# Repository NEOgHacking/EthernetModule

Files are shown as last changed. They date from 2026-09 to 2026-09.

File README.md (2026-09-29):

# EthernetModule
This is a custom Ethernet module for the hackxpansion console made by @koeg. It has been created with some simple components. It was made for the purpose of having internet on the hackxpansion console via wire, or even to have local multiplayer.

## Design
This module has been designed with the following requirements and components
single slot hackxpansion module
W5500 PHY ic communicating over spi
Ethernet port with integrated magnetics
length and impedance matched
up to 100Mb/s speed

## Schematic



## PCB




## Case

https://cad.onshape.com/documents/23acd3255b900cc5b85fa1fc/w/7ef244823df79fb773706f50/e/06be5b5812756bedfbe98cc1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





## Code
I used the tutorial on the first driver heavily when writing the code for this module.

# Credits
# **@KOEG**

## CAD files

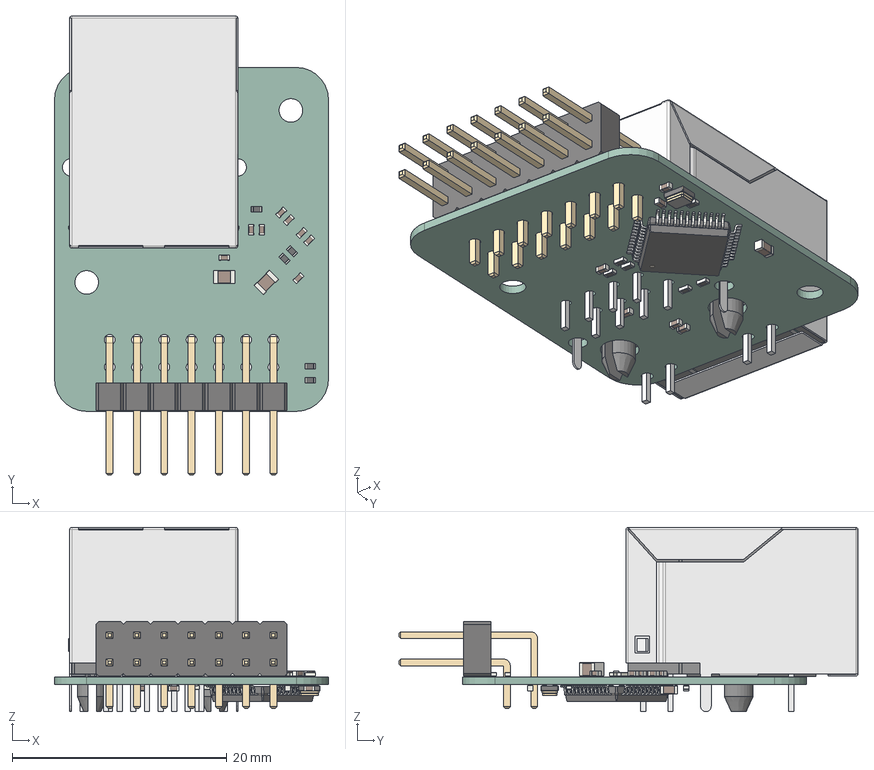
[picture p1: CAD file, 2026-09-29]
pcb/Ethernet_interface.step
25.5 x 42.7 x 17.1 mm
R_0402_1005Metric x 11
C_0402_1005Metric x 14
RJ45-TH_HR911105A
C_0805_2012Metric x 2
PinHeader_2x07_P254mm_Horizontal
LQFP-48_7x7mm_P0.5mm
Crystal_SMD_2016-4Pin_2.0x1.6mm
C_0603_1608Metric
Ethernet_interface_PCB

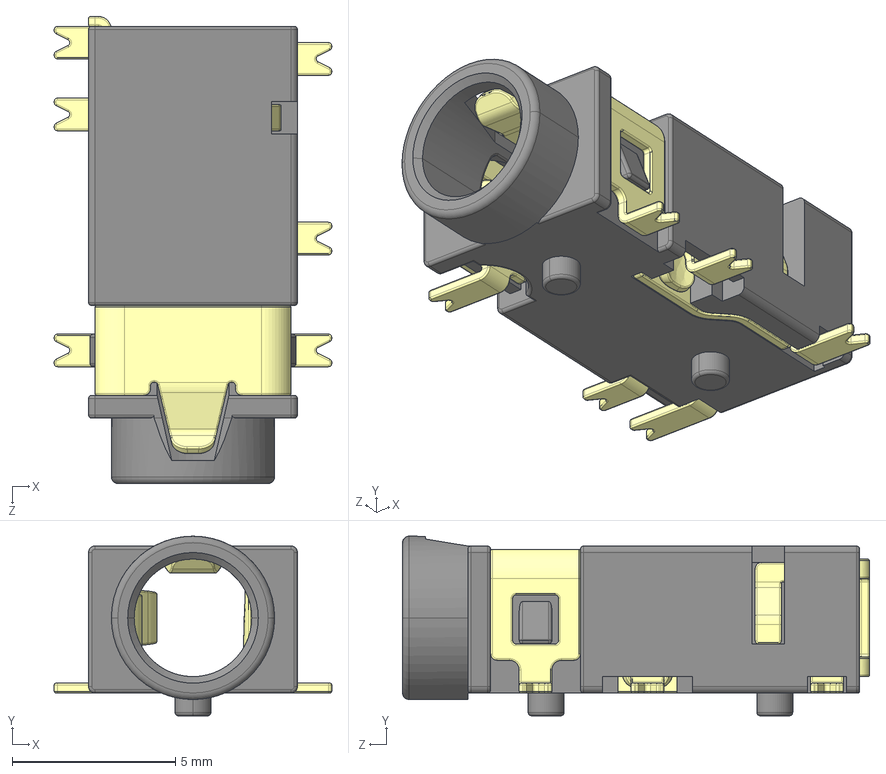
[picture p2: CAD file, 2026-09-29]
pcb/kicad_lib/PJ311D_WPos.STEP
8.50 x 5.50 x 14.3 mm
001^PJ311D_WPos
002^PJ311D_WPos
003^PJ311D_WPos
004^PJ311D_WPos
005^PJ311D_WPos
006^PJ311D_WPos
007^PJ311D_WPos

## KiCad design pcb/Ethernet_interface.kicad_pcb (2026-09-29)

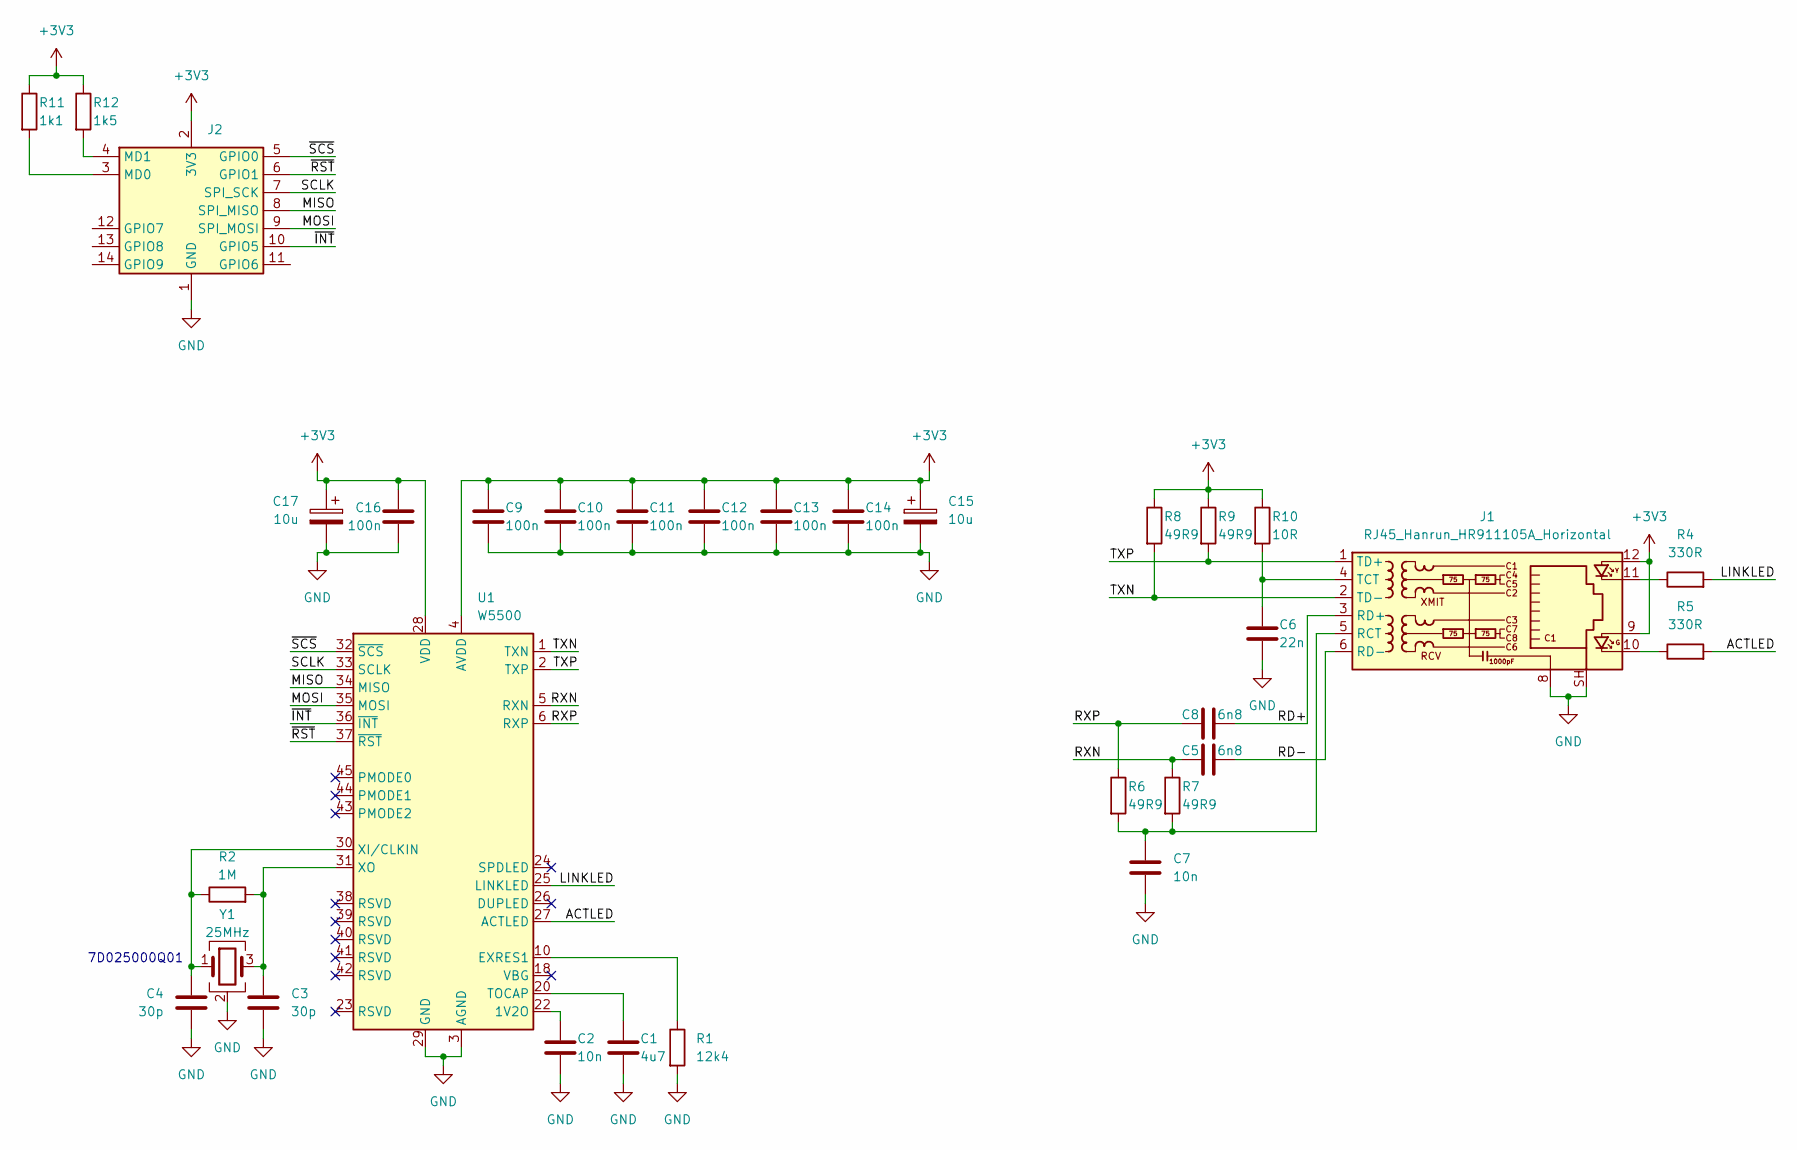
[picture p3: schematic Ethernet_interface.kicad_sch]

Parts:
C1: 4u7; C_0603_1608Metric
C2, C7: 10n; C_0402_1005Metric
C3, C4: 30p; C_0402_1005Metric
C5, C8: 6n8; C_0402_1005Metric
C6: 22n; C_0402_1005Metric
C9, C10, C11, C12, C13, C14, C16: 100n; C_0402_1005Metric
C15, C17: 10u; C_0805_2012Metric; LCSC C1969735
J1: RJ45_Hanrun_HR911105A_Horizontal; LCSC C12074
J2: PinHeader_2x07_P2.54mm_Horizontal
R1: 12k4; R_0402_1005Metric
R2: 1M; R_0402_1005Metric
R4, R5: 330R; R_0402_1005Metric
R6, R7, R8, R9: 49R9; R_0402_1005Metric
R10: 10R; R_0402_1005Metric
R11: 1k1; R_0402_1005Metric
R12: 1k5; R_0402_1005Metric
U1: W5500; LQFP-48_7x7mm_P0.5mm; LCSC C32843
Y1: 25MHz; Crystal_SMD_2016-4Pin_2.0x1.6mm; LCSC C648942

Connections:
+3V3: C9.1, C10.1, C11.1, C12.1, C13.1, C14.1, C15.1, C16.1, C17.1, J1.9, J1.12, J2.2 (3V3), R8.1, R9.1, R10.1, R11.1, R12.1, U1.4 (AVDD), U1.8 (AVDD), U1.11 (AVDD), U1.15 (AVDD), U1.17 (AVDD), U1.21 (AVDD), U1.28 (VDD)
/ACTLED: R5.2, U1.27 (ACTLED)
/LINKLED: R4.2, U1.25 (LINKLED)
/MISO: J2.8 (SPI_MISO), U1.34 (MISO)
/MOSI: J2.9 (SPI_MOSI), U1.35 (MOSI)
/RD+: C8.2, J1.3 (RD+)
/RD-: C5.2, J1.6 (RD-)
/RXN: C5.1, R7.1, U1.5 (RXN)
/RXP: C8.1, R6.1, U1.6 (RXP)
/SCLK: J2.7 (SPI_SCK), U1.33 (SCLK)
/TXN: J1.2 (TD-), R8.2, U1.1 (TXN)
/TXP: J1.1 (TD+), R9.2, U1.2 (TXP)
/~INT: J2.10 (GPIO5), U1.36 (~INT)
/~RST: J2.6 (GPIO1), U1.37 (~RST)
/~SCS: J2.5 (GPIO0), U1.32 (~SCS)
GND: C1.2, C2.2, C3.2, C4.2, C6.2, C7.2, C9.2, C10.2, C11.2, C12.2, C13.2, C14.2, C15.2, C16.2, C17.2, J1.8, J1.SH, J2.1 (GND), R1.2, U1.3 (AGND), U1.9 (AGND), U1.14 (AGND), U1.16 (AGND), U1.19 (AGND), U1.29 (GND), U1.48 (AGND), Y1.2 (G), Y1.4 (G)
unnamed: J1.10, R5.1
unnamed: J1.11, R4.1
unnamed: C7.1, J1.5 (RCT), R6.2, R7.2
unnamed: C6.1, J1.4 (TCT), R10.2
unnamed: J2.3 (MD0), R11.2
unnamed: J2.4 (MD1), R12.2
unnamed: C2.1, U1.22 (1V2O)
unnamed: R1.1, U1.10 (EXRES1)
unnamed: C1.1, U1.20 (TOCAP)
unnamed: C4.1, R2.1, U1.30 (XI/CLKIN), Y1.1
unnamed: C3.1, R2.2, U1.31 (XO), Y1.3

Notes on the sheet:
7D025000Q01

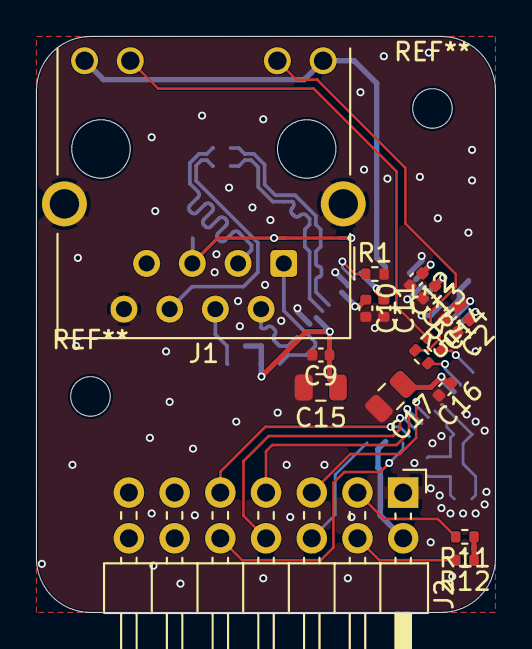
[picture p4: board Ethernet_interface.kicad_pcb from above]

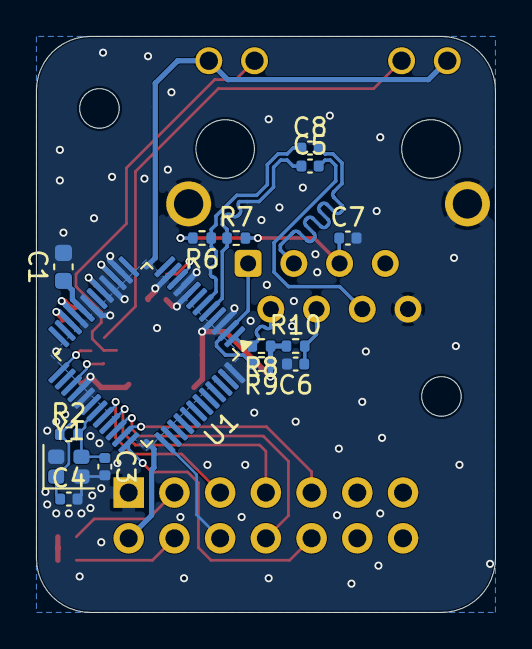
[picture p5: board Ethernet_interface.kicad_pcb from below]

Board: 2 copper layers, 25.5 x 32.0 mm, 32 parts (15 on the bottom side), 27 nets.

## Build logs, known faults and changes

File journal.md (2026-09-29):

# Journal 1 20m

# Brainstorm
So long story short i wanted internet and specifically Ethernet because who doesn't love a wire :yay: Well i did a bit of digging and most of the phys i found used in most devices need a special part in the microcontroller so to prevent that i went for the good old W5500 SPI ethernet phy. Then i went for the best selling Ethernet connector with integrated magnetics.



Apart from that it will be a very tight module but o well challenges are fun.

# Journal 2 90m

# Schematic
So at first i laid out all the ic's and connectors i needed. With the things i choose in the last journal



Then i started following the datasheet of the W5500 for the right capacitances and resistances needed for the different pins used first i started with the pins that were defined what stuff they needed in the pinout diagram.



Then i found the specs of the crystal i needed. I directly implemented that into the schematic as per datasheet rules.



After this i dug a bit deeper and did allot of decoupling for the voltage in.



Then i started on the Ethernet connector, at first i did the status leds for the ethernet connector so it would show the rights stuff you would expect it to show.



Then i started on the hardest part, the decoupling and resistors needed for the tx and rx pairs of the Ethernet connection, this is after 2 times still black magic for me but i just follow the datasheet of the W5500.



After some tries i got it done and had it laid out nicely that i was happy with.



Then i did the right labels for the Ethernet ic, the spi pins and the reset pins ext. the rest i stopped of with those cross thingies.



Now it was time to connect it to the module connector. This was a bit of a unknown. I only connected the pins that would need to go to specific pins so i could choose the pinout for the others while doing the PCB design so it would match the PCB better.



Then at the end a total of the schematic.



# Journal 3 300m

# PCB layout and routing

At first i started with the layout of the bigest components like the network connector the ic and the expansion connector, these would be the most irritatingly in the way so i wanted to get them out of the way as soon as possible.



Then i started with routing the most important traces off them all the ethernet pairs. I used the calculator from jlcpcb to calculate the impedance needed, tho for this short length it wouldn't matter much.



now it was time to do the next thing This was where i would want all the components, i also looked at other ethernet connectors but 90% of them where to long so this was the way to go.



Then i started with decoupling the ic and also adding the crystal for the ic, i decided on a 2 sided pcb because of the space constraints.



Now i had some more components placed down i needed to length match the tx trace, i did this and this worked, but just barely.



Next things next I started thinking about how i wanted to lay out the rx trace, it was really aquard spot and i had tried a few different things. Here i had a general idea of where i wanted the components that where needed in between the rx and tx traces.



The next picture was a small step of brainstorming the ethernet traces.



Then i routed the RX side and found out this is what i had to deal with.



So i tried a few different things but ended up here with this botched up trace so + and - of the RX trace would line up.



Then it was time for some length matching, and some was an understatement, 5mm for this was crazy but eah its what we have to do, im just gradefull i didn't need to lenght match rx to tx that would be terror.



Now time for the length matching here is its beutifull sight.



Then i routed the 3.3V power trace and the spi bus.



Now at the end, here are a few final pictures of the end product.











# Credits

# @KOEG

# Journal 4 60m

# Case

At first i imported the pcb into onshape as a step file with the 3d models so i could base the case off the 3d models.



Then i created a sketch that had a perimeter and some other features all included in the sketch so it would only take a few extrudes to finish it.



Then i extruded the perimeter on the outside of the case.



Now i created a top so it wouldn't be a open module.



Now it looked like this a bit not so nice, i wanted to create some fillits so it looked a bit nicer and here is a before and after.





# Credits

# **@KOEG**

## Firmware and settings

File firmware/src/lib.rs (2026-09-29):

#![no_std]

use xpanse_api::{
    bus::{allocator::BusAllocator, spi::SpiBusHandle},
    driver::{Driver, DriverError, DriverMeta},
    gpio_bank::{BankPins, GpioBank},
    metadata::{ModuleDetectResistor, ModuleID, ModuleSlot},
    reexports::embassy_rp::{
        gpio::{Level, Output},
        spi,
    },
    registry::Registry,
};

pub const SPI_SCK_GPIO: u8 = 2;
pub const SPI_MISO_GPIO: u8 = 3;
pub const SPI_MOSI_GPIO: u8 = 4;
pub const W5500_CS_GPIO: u8 = 0;

const COMMON_REG_BLOCK: u8 = 0;
const VERSION_REGISTER: u16 = 0x0039;
const EXPECTED_VERSION: u8 = 0x04;

pub struct EthernetDriver;

impl DriverMeta for EthernetDriver {
    const ID: ModuleID = ModuleID {
        md0: ModuleDetectResistor::R1K1,
        md1: ModuleDetectResistor::R1K5,
    };
}

pub struct W5500 {
    spi: SpiBusHandle,
    cs: Output<'static>,
}

impl W5500 {
    fn new(spi: SpiBusHandle, cs: Output<'static>) -> Self {
        Self { spi, cs }
    }

    pub async fn read_register(&mut self, block: u8, address: u16) -> Result<u8, W5500Error> {
        let mut value = [0];
        self.read(block, address, &mut value).await?;
        Ok(value[0])
    }

    pub async fn write_register(
        &mut self,
        block: u8,
        address: u16,
        value: u8,
    ) -> Result<(), W5500Error> {
        self.write(block, address, &[value]).await
    }

    pub async fn version(&mut self) -> Result<u8, W5500Error> {
        self.read_register(COMMON_REG_BLOCK, VERSION_REGISTER).await
    }

    pub async fn is_present(&mut self) -> Result<bool, W5500Error> {
        Ok(self.version().await? == EXPECTED_VERSION)
    }

    pub async fn read(
        &mut self,
        block: u8,
        address: u16,
        data: &mut [u8],
    ) -> Result<(), W5500Error> {
        let header = make_header(block, address, false)?;
        self.cs.set_low();
        let result = async {
            self.spi.write(&header).await.map_err(W5500Error::Spi)?;
            self.spi.read(data).await.map_err(W5500Error::Spi)
        }
        .await;
        self.cs.set_high();
        result
    }

    pub async fn write(&mut self, block: u8, address: u16, data: &[u8]) -> Result<(), W5500Error> {
        let header = make_header(block, address, true)?;
        self.cs.set_low();
        let result = async {
            self.spi.write(&header).await.map_err(W5500Error::Spi)?;
            self.spi.write(data).await.map_err(W5500Error::Spi)
        }
        .await;
        self.cs.set_high();
        result
    }
}

#[derive(Debug, Clone, Copy, PartialEq, Eq)]
pub enum W5500Error {
    Spi(xpanse_api::bus::spi::SpiError),
    InvalidBlock(u8),
}

fn make_header(block: u8, address: u16, is_write: bool) -> Result<[u8; 3], W5500Error> {
    if block > 0x1f {
        return Err(W5500Error::InvalidBlock(block));
    }

    let control = (block << 3) | if is_write { 0x04 } else { 0 };
    Ok([(address >> 8) as u8, address as u8, control])
}

impl<G: BankPins> Driver<G> for EthernetDriver {
    async fn create(
        gpio_bank: GpioBank<G>,
        slot: ModuleSlot,
        registry: &mut Registry,
        bus_allocator: &mut BusAllocator,
    ) -> Result<(), DriverError> {
        let cs = Output::new(gpio_bank.gpio0.into(), Level::High);
        let mut spi_config = spi::Config::default();
        spi_config.frequency = 100_000;

        let spi = bus_allocator
            .create_spi_bitbang(
                gpio_bank.gpio2.into(),
                gpio_bank.gpio4.into(),
                gpio_bank.gpio3.into(),
                spi_config,
            )
            .map_err(|_| DriverError::InitFailed)?;

        let mut w5500 = W5500::new(spi, cs);
        if !w5500
            .is_present()
            .await
            .map_err(|_| DriverError::InitFailed)?
        {
            return Err(DriverError::InitFailed);
        }

        registry.register(slot, Self::ID, w5500);
        Ok(())
    }
}

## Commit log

2026-09-29 first and last commit
    [Ethernet_interface.kicad_pcb, Ethernet_interface.kicad_sch, Ethernet_interface.step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]
2026-10-01 fixed small things
    [Ethernet_interface.kicad_sch]
2026-10-12 Added cad and fixed small pcb issues
2026-10-12 Added BOM and made production files for pcb
